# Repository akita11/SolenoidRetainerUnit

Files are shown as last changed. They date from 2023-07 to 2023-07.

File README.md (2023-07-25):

# SolenoidRetainerUnit

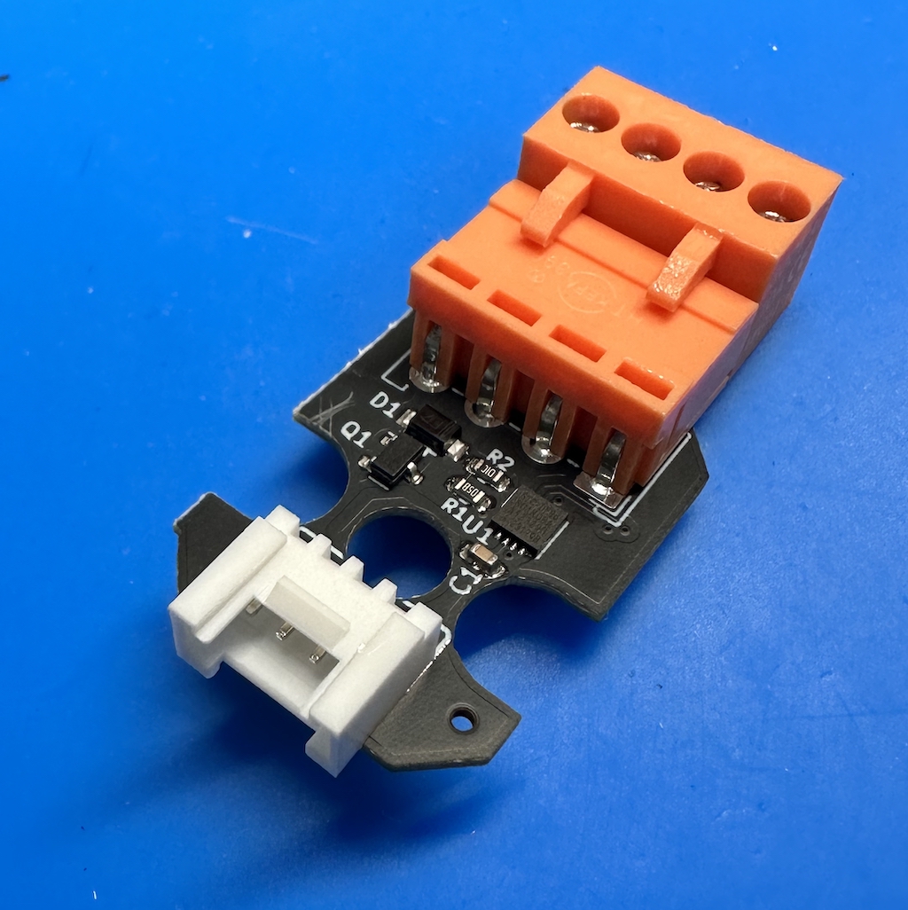
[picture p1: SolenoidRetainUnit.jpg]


[タカハのスリムロック](https://www.takaha.co.jp/co/product-slim-lock/)等の負荷を、「最初短い時間通電したあとは、弱く通電する」という制御を行います。スリムロックでは、通電するとロックが解除されますが、通電を解除すると、再び押し込めばロックされます。「ロックが解除された状態を維持したいが、通電しつづけると負荷に負担がかかる（スリムロックは長時間通電すると、内部の部品が熱で変形して使えなくなります）」という場合に。PWM駆動で「弱く通電した状態」を維持します。（[スイッチサイエンスで委託販売中](https://www.switch-science.com/products/9147)です）

基板形状が「[M5Stack用VH3.96-4ピンユニット](https://www.switch-science.com/products/4055)」と同一のため、そのケースを使うことができます。

## 使い方

オレンジ色のコネクタ(VH3.96-4p)に、負荷用の電源と負荷を接続します。M5Stackの[BAVGソケット](https://www.switch-science.com/products/7234)を使うと、電源は2.1mmプラグ、負荷はスプリング端子で接続できて便利です。

Grove端子のピン配置は以下のとおりです。
- 1. GND
- 2. VDD(3.3〜5V)
- 3. 未使用（内部でVDDにプルアップ）
- 4. 制御入力（内部でVDDにプルアップ）

「4.制御入力」を"0"にすると、最初の200msだけ負荷をONにし、そのあとは、「4.制御入力」が"0"の間はデューティー比10%でPWM駆動します。「4.制御入力」を"1"（または開放）とすると、負荷をOFFにします。

## プログラムの書き換え

このボードは、回路図をみるとわかるように、マイコン(STC8G1K08A)と負荷駆動用のMOSFETからなります。つまりマイコンのプログラム次第で、負荷を自由に制御することができます。

初期状態で書き込んであるプログラムはフォルダFW以下にありますので、必要であればこれを元に改造してください。Grove端子の2本の信号線はマイコンのUART端子につなげてあります。

マイコンSTC8G1K08Aのプログラム開発・書き込みは[こちらの記事](https://note.com/akita11/n/n41316faaaf19)などを参考にしてください。

## Author

Junichi Akita (akita@ifdl.jp, @akita11)

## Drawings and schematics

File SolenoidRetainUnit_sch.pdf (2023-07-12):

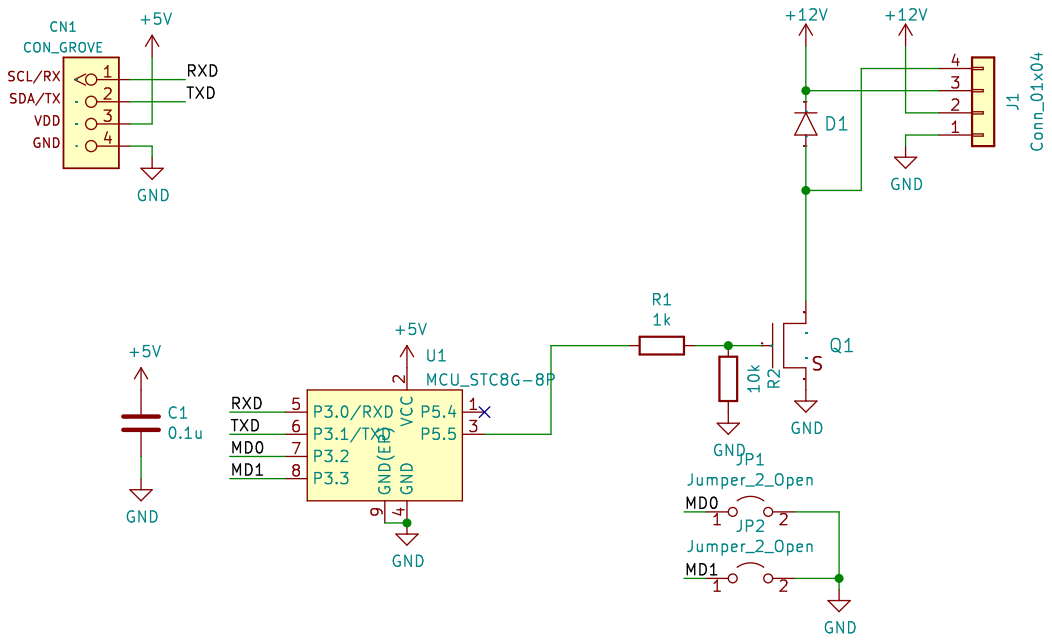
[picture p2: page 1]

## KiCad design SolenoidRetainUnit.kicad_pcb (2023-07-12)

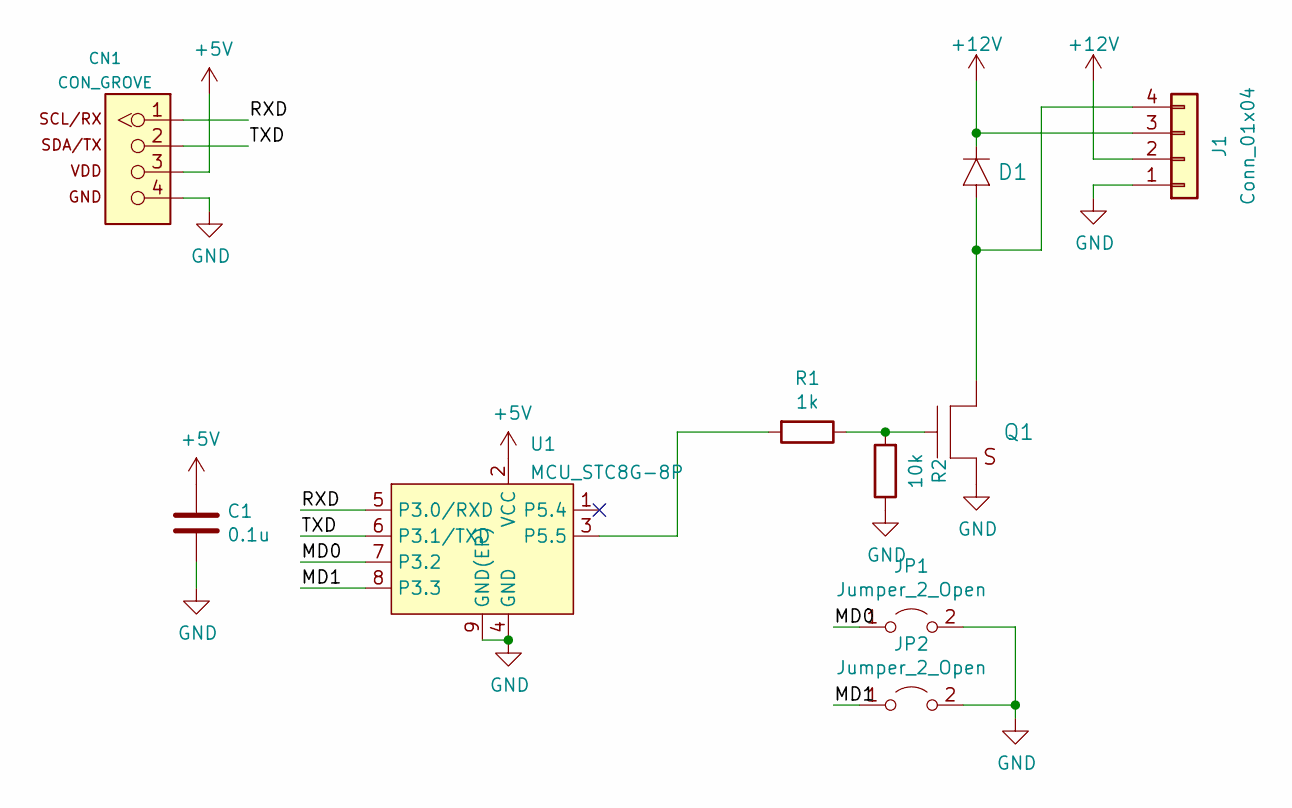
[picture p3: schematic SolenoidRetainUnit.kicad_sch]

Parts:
C1: 0.1u; C_0603_1608Metric; LCSC C14663
CN1: CON_GROVE; CON_GROVE_H
D1: DIODE; D_SOD123FL; LCSC C2760867
J1: Conn_01x04; JST_VH_S4P-VH_1x04_P3.96mm_Horizontal
JP1, JP2: Jumper_2_Open; SolderJumper-2_P1.3mm_Open_Pad1.0x1.5mm
Q1: TR_NMOS_IRLML6344; SOT-23; LCSC C20917
R1: 1k; R_0603_1608Metric; LCSC C22764
R2: 10k; R_0603_1608Metric; LCSC C25804
U1: MCU_STC8G-8P; DFN-8-1EP_3x3mm_P0.5mm_EP1.65x2.38mm; LCSC C915664

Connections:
+5V: C1.1, CN1.3, U1.2 (VCC)
+12V: D1.K, J1.2, J1.3
/MD0: JP1.1 (A), U1.7 (P3.2)
/MD1: JP2.1 (A), U1.8 (P3.3)
/RXD: CN1.1, U1.5 (P3.0/RXD)
/TXD: CN1.2, U1.6 (P3.1/TXD)
GND: C1.2, CN1.4, J1.1, JP1.2 (B), JP2.2 (B), Q1.2 (S), R2.1, U1.4 (GND), U1.9 (GND(EP))
unnamed: D1.A, J1.4, Q1.3 (D)
unnamed: Q1.1 (G), R1.1, R2.2
unnamed: R1.2, U1.3 (P5.5)

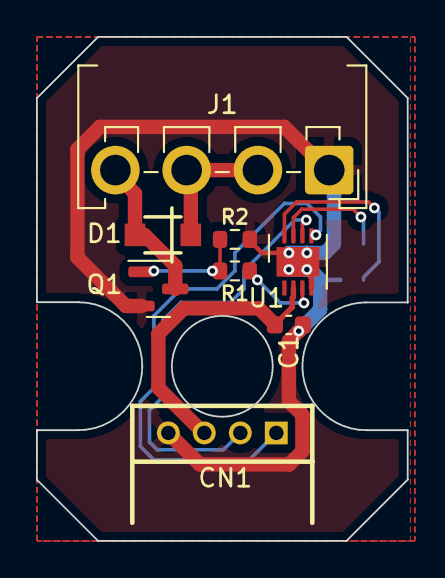
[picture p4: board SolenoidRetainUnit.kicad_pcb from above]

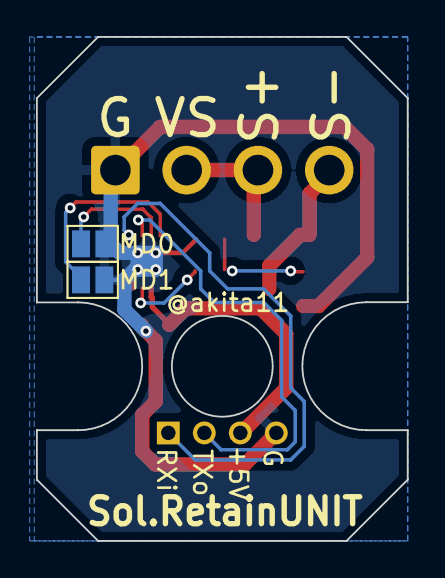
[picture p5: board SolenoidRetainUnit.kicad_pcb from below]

Board: 2 copper layers, 20.6 x 28.0 mm, 10 parts (2 on the bottom side), 10 nets.

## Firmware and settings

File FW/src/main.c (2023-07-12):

#include <stdint.h>
#include "fw_reg_stc8g.h"

// STC8G1K08A-36I-DFN8
// Grove: RXD(P3.0)-TXD(P3.1)-VDD-GND / RXD for control (1=on / 0=off)

// 起動時の通電→PWM駆動のパラメータ。時間の単位は[0.005ms]
#define T_ON   40000 // 起動時の通電時間 (0.005ms * 40000 = 200ms)
#define TON_0  1    // PWM駆動時の"1"の時間 (例：0.005ms * 1 = 0.005ms)
#define TOFF_0 9    // PWM駆動時の"0"の時間 (例：0.005ms * 9 = 0.045ms)
// 備考
// - PWM駆動の周期は "TON_0 + TOFF_0"で決まる（この例では0.05ms * (1+9) = 0.05ms、つまり周波数は20kHz）
// - PWM駆動のデューティー比は "TON_0 / (TON_0 + TOFF_0)"で決まる（この例では、1 / (1+9) = 10%）

// コンパイラのインストール
// - Mac・Linux: こちらの"sdcc"と"binutils"のインストール手順: https://github.com/creeper0723/Ksylitoli
// - Windows: http://sdcc.sourceforge.net/ からインストール（未検証）

//-----------------------
//以下は編集不要

#define pinLOAD P55 // P5.4 / CCP2_3
#define pinMD0  P32 // P3.2
#define pinMD1  P33 // P3.3
#define pinRXD  P30 // P3.0 / Grove-p1
#define pinTXD  P31 // P3.1 / Grove-p2


#define TON_1  2
#define TOFF_1 18
#define TON_2  3
#define TOFF_2 27
#define TON_3  4
#define TOFF_3 36

#define FOSC 11059200UL

volatile uint16_t cnt = 0;
volatile uint8_t f = 0;
uint8_t Ton, Toff;

// 200kHz (5us)
void Timer0_ISR(void) __interrupt 1 // Timer0 interrupt
//void Timer0_ISR(void) __interrupt // Timer0 interrupt
{
  f = 1;
}

// wait for [x 5us]
void delay_5us(uint16_t t)
{
  cnt = 0;
  TR0 = 1;
  while(t-- > 0){
    f = 0; while(f == 0);
  }
  TR0 = 0;
}

void main()
{
  uint32_t Ton, Toff;
  P3M1 = 0x00; P3M0 = 0x00; // set P3.0-3.3 as as quasi-bidirectional
  P5M1 = 0x00; P5M0 = 0x20; // set P5.5 as push-pull output

  TMOD = 0x02; // set Timer0 as 8bit timing mode (counting-down, TL0=counter, TH0=reload value)
  AUXR |= 0x80; // T0x12=1 / SYSclk/12 = 11.06MHz
  TH0 = 255 - 56; // Timer0 interrupt = 197.5kHz (11.06MHz / 56)
  TL0 = TH0;
  EA = 1;
  ET0 = 1;
  TR0 = 1;
  Ton = TON_0;   // default PWM value
  Toff = TOFF_0; //  default PWM value
  pinLOAD = 0;
  
  while(1) {
    P3 |= 0x0f; // enable P3.0-3 pull-up
    __asm__("nop");
    __asm__("nop");
    if (pinRXD == 0){
      pinLOAD = 1;
      delay_5us(T_ON); // initial ON
      pinLOAD = 0;
      while(pinRXD == 0){
	P3 |= 0x0f; // enable P3.0-3 pull-up
	__asm__("nop");
	__asm__("nop");
	pinLOAD = 1;
	delay_5us(Ton); // initial ON
	pinLOAD = 0;
	delay_5us(Toff);
      }
    }
  }
}
